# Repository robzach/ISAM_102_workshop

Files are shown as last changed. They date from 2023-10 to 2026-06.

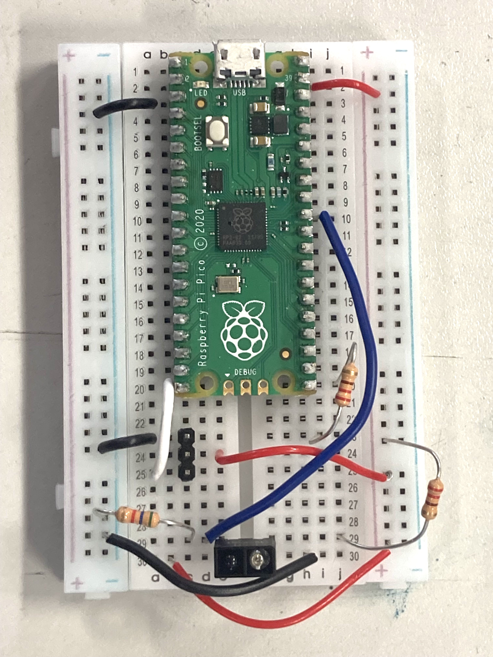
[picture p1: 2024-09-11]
product documentation images/Raspberry Pi Pico.jpg

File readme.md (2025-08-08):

# ISAM 102 Workshop

This repository contains files relevant to the ISAM 102 Workshop, offered as part of the [ISAM (International Symposium on Academic Makerspaces)](https://isam2025.hemi-makers.org/) conference hosted at the University of California, Berkeley on August 6, 2025.

## Key links

* [The workshop slide deck](https://docs.google.com/presentation/d/1lfgx7r61DBWelSqBV9T8WLAmH33UfCxg_Bofop4bHoo/edit?usp=sharing) gives a good overview of the project
* [Bill of materials](https://docs.google.com/spreadsheets/d/1Q51IumBE_j06Qix7HolaOQdSv1IBVW_yVcd7gR8xeUc/edit?usp=sharing) including costs and sources
* Most design files are contained in this repo, organized by the design software used. Our Fusion designs are viewable (and downloadable) below:
  + [Full assembly](https://a360.co/4ouuBFh)
  + [Updated chassis base](https://a360.co/45b6XpY)

## Workshop leaders

* [Robert Zacharias](https://www.andrew.cmu.edu/user/rzachari), Assistant Teaching Professor, Entertainment Technology Center and IDeATe (Integrative Design, Arts, and Technology), Carnegie Mellon University
* [Bill Nace](https://www.ece.cmu.edu/directory/bios/nace-bill.html), Teaching Professor, Electrical and Computer Engineering, Carnegie Mellon University

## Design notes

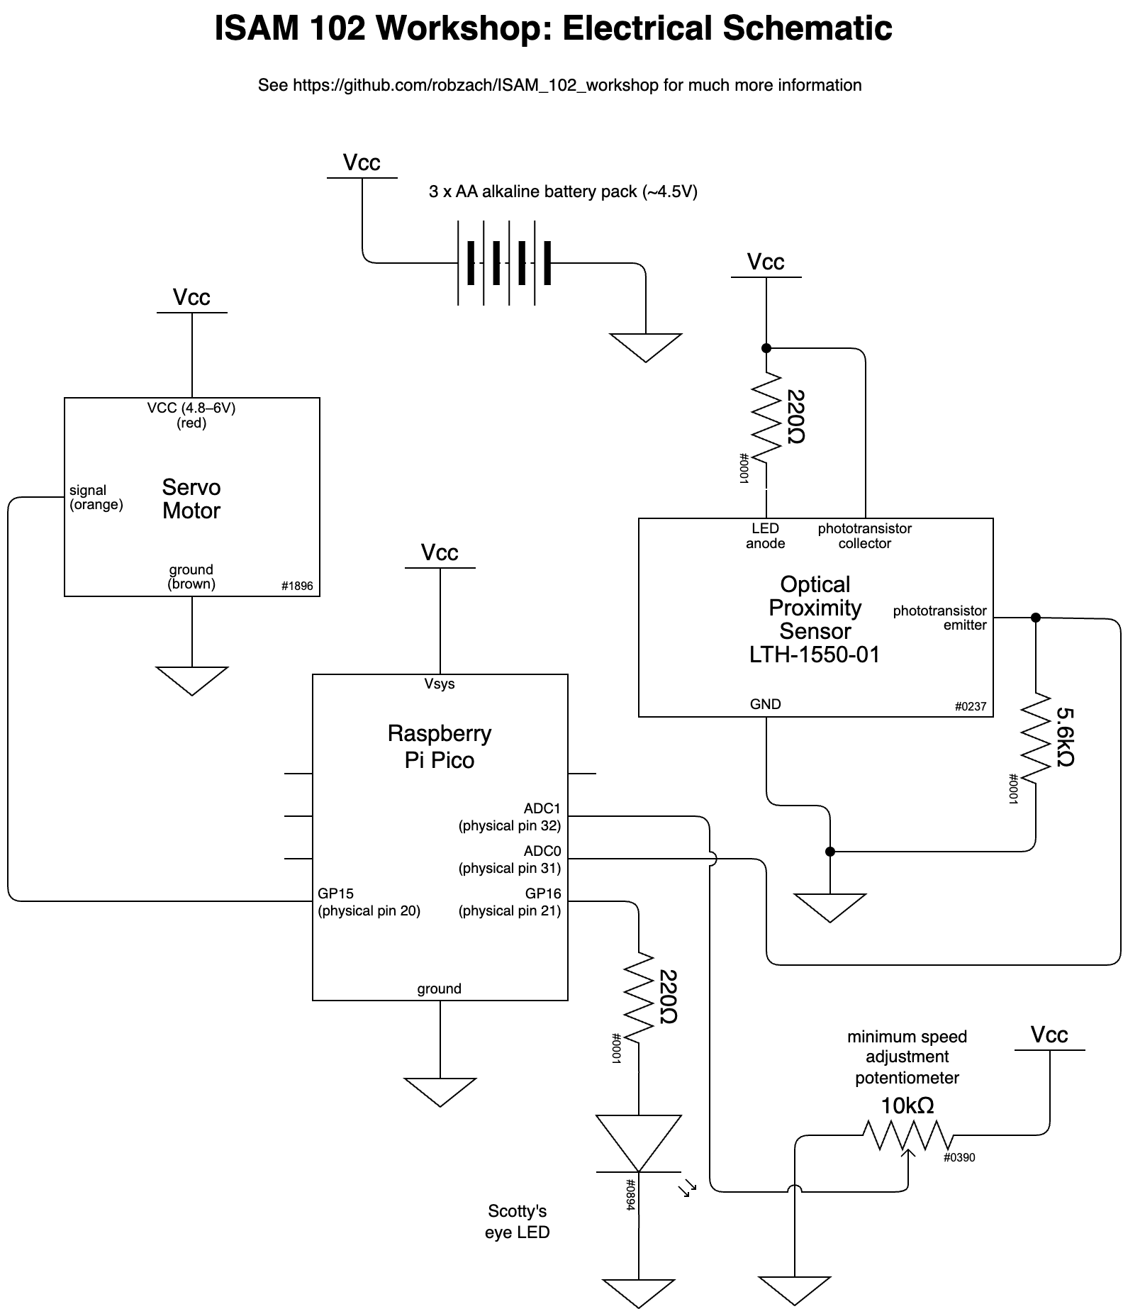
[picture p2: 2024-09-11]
design source files/Draw.ioref.org/ISAM 102 schematic.drawio.png

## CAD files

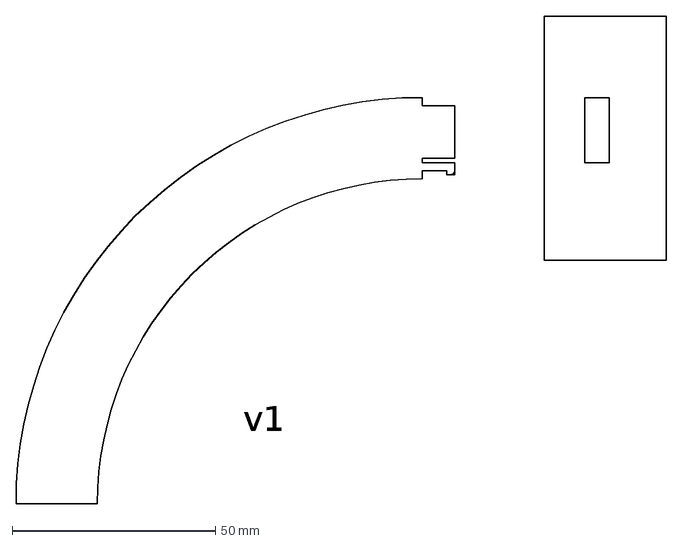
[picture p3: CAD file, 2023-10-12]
design source files/LibreCAD/spring tab 9-22-23.dxf
v1

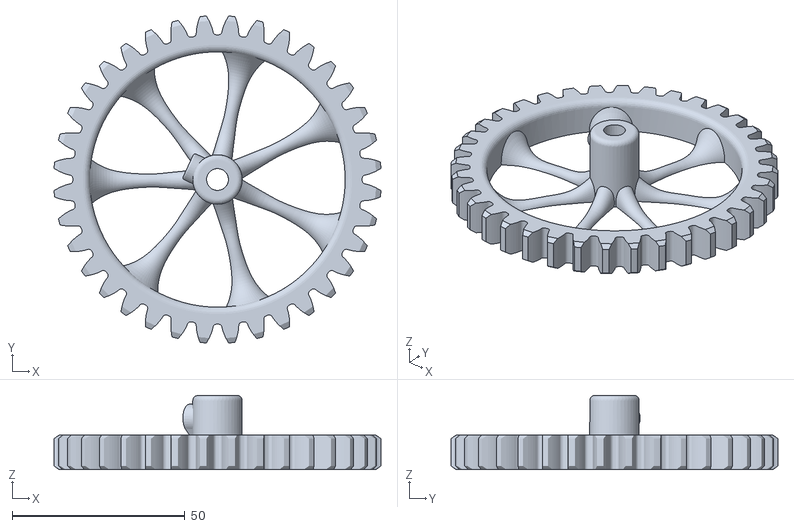
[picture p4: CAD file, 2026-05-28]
production files/D6_gear36Tooth.stl
94.8 x 94.8 x 21.5

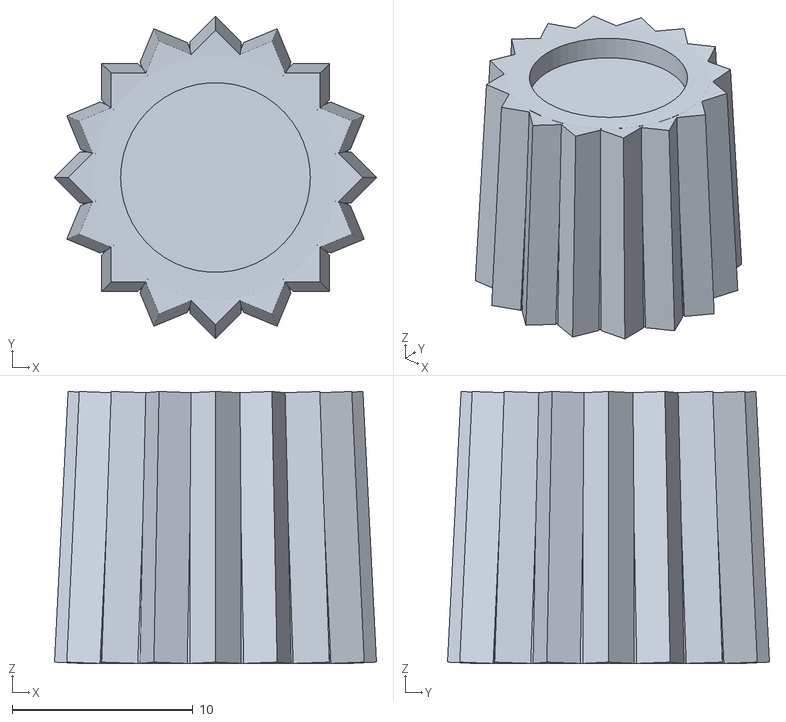
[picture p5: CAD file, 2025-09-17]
production files/knobs/knob_h15_t10_c1.stl
17.8 x 17.8 x 15.1

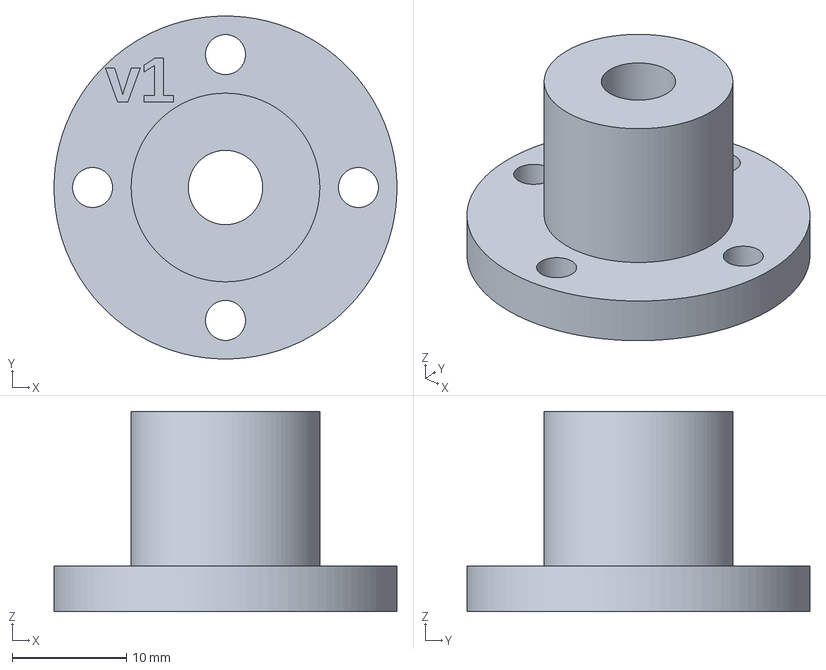
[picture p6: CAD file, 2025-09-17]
production files/D7_shaftHubNoClamp.3mf
30.0 x 30.0 x 17.5 mm

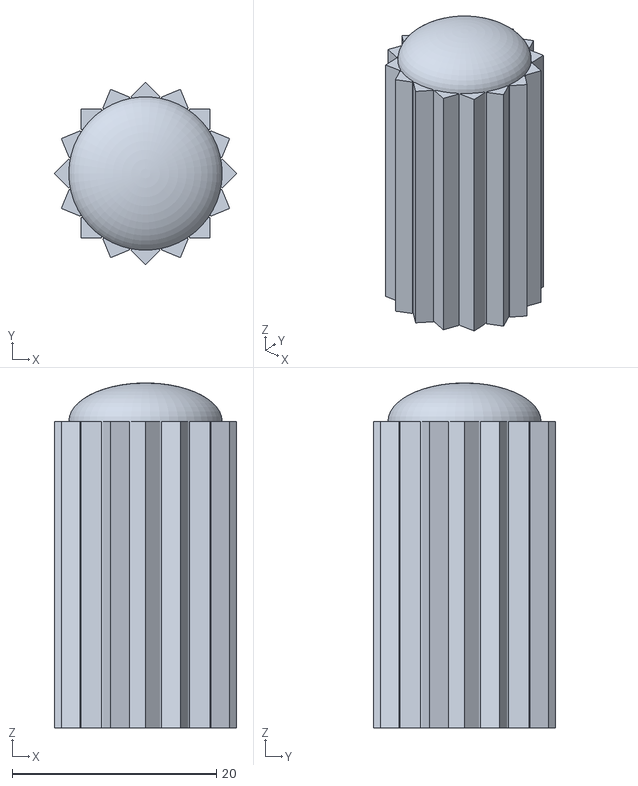
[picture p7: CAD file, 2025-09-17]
production files/knobs/knob_h30_t0_c2.stl
17.8 x 17.8 x 33.7

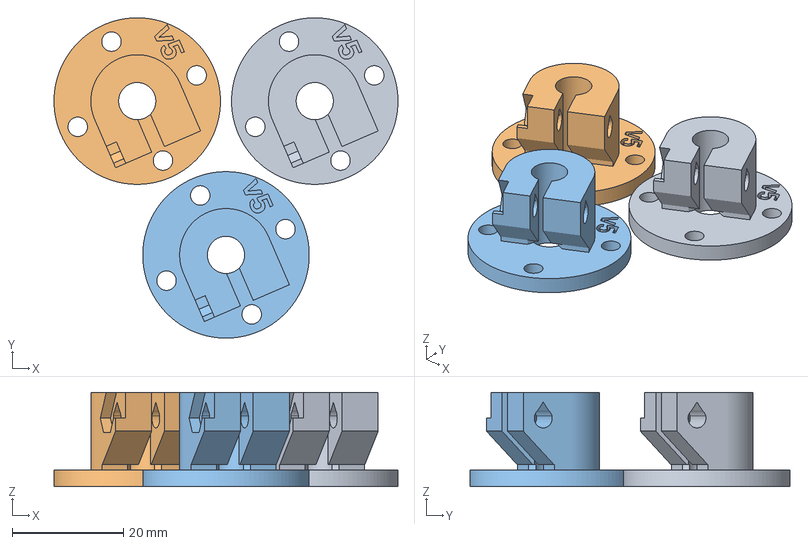
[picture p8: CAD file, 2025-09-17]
production files/D1_shaftHubClamping.3mf
62.0 x 57.7 x 17.0 mm
parameterized hub design v5.stl x 3

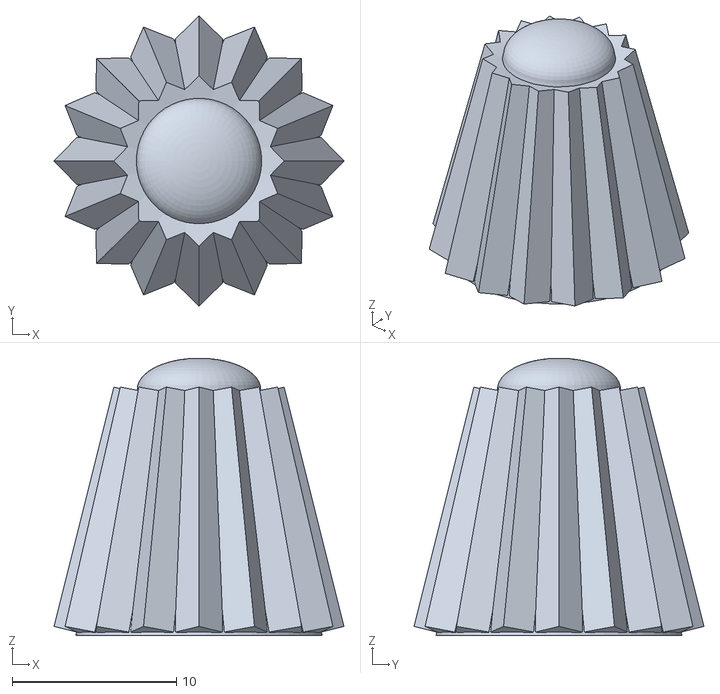
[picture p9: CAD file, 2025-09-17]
production files/knobs/knob_h15_t50_c2.stl
17.6 x 17.6 x 16.9

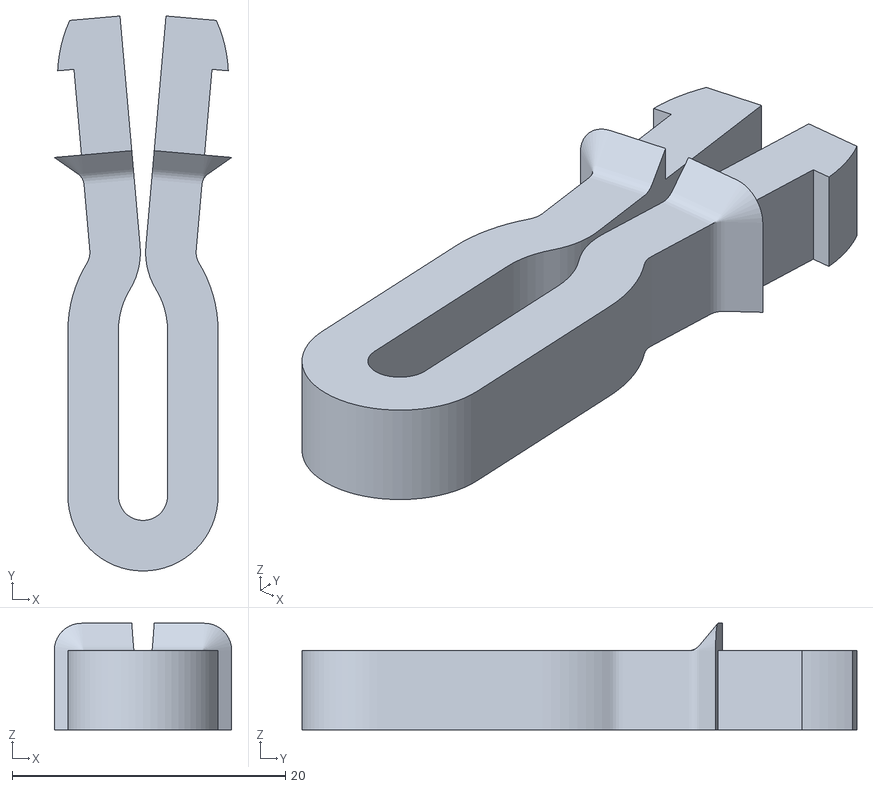
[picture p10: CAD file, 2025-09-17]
production files/D2a_smallTailLoop.stl
13.0 x 40.6 x 7.80

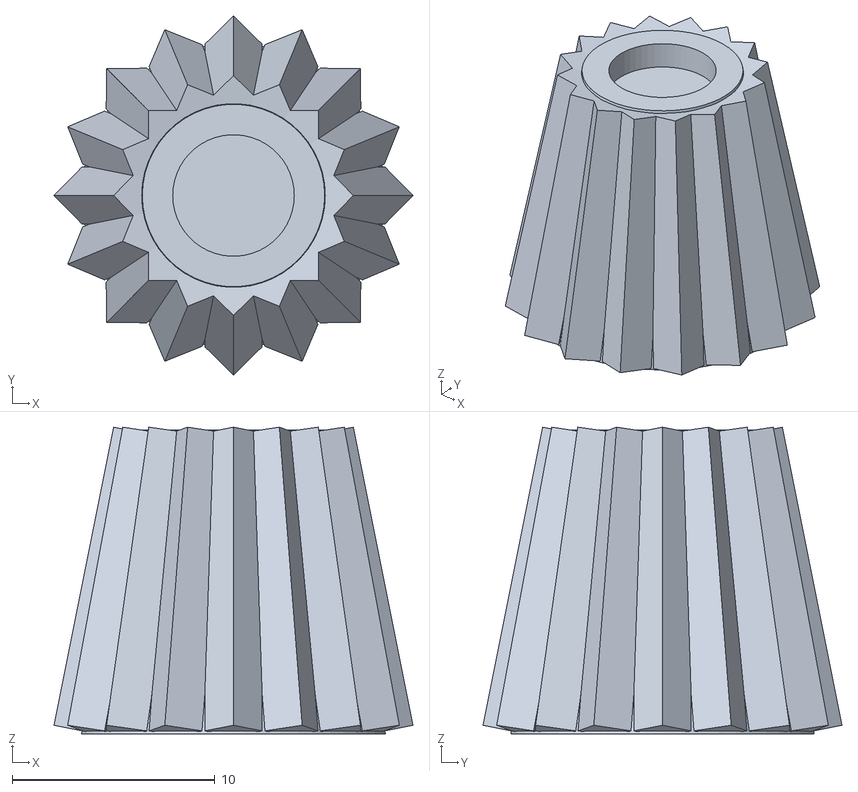
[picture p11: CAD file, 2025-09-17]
production files/knobs/knob_h15_t40_c1.stl
17.7 x 17.7 x 15.1

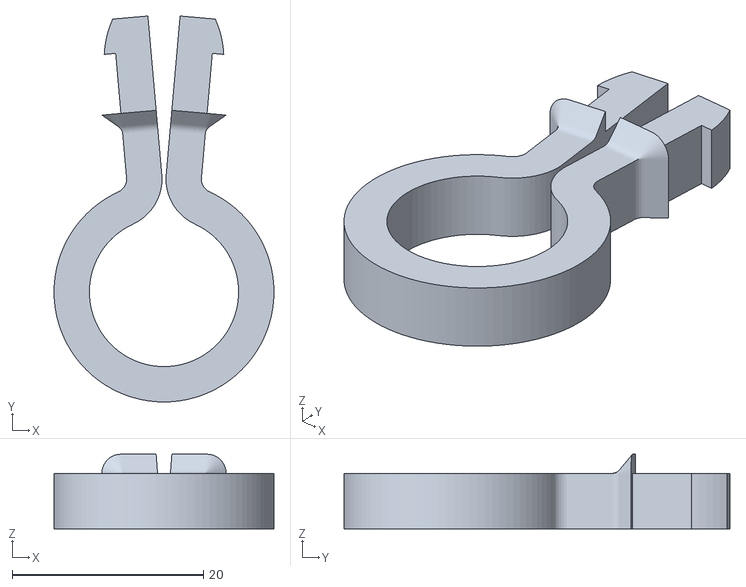
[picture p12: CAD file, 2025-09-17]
production files/D2b_circularTailLoop.stl
23.0 x 40.4 x 7.80

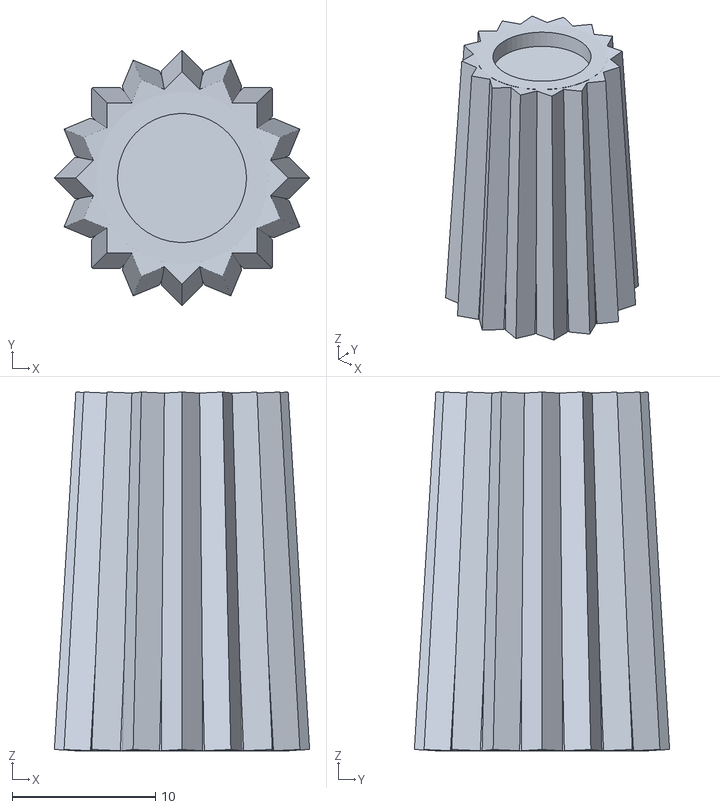
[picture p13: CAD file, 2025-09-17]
production files/knobs/knob_h25_t20_c1.stl
17.8 x 17.8 x 25.1

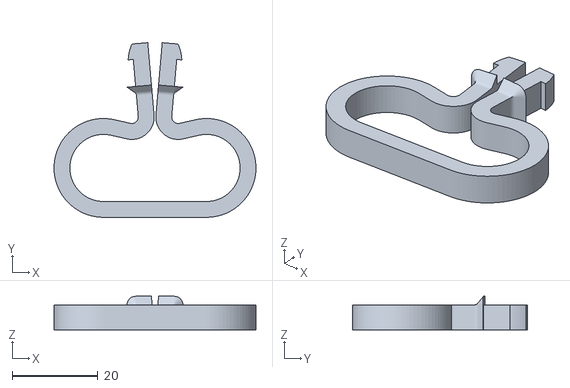
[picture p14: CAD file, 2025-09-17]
production files/D2c_largeTailRing.stl
47.0 x 40.6 x 7.80

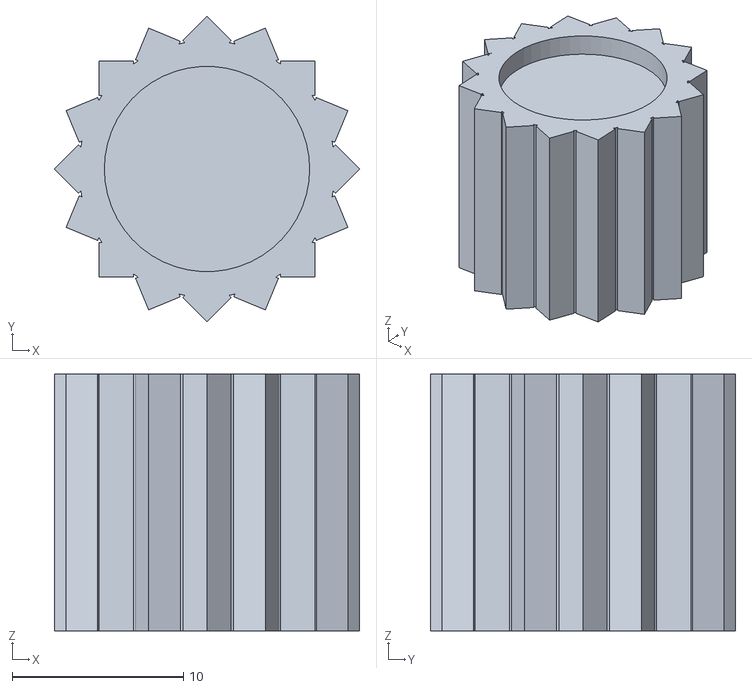
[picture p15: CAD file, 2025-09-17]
production files/knobs/knob_h15_t0_c1.stl
17.8 x 17.8 x 15.0

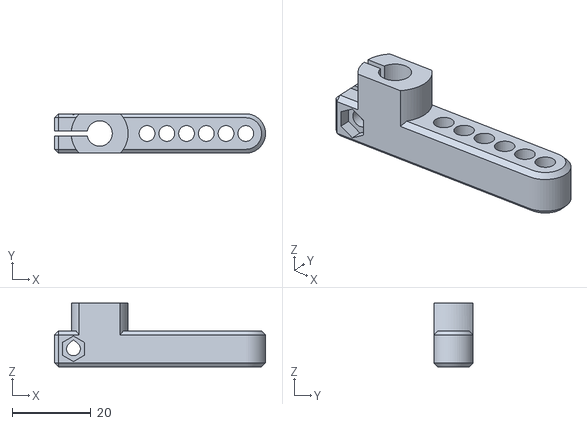
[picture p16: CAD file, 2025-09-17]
production files/D3_tailRotor.stl
53.4 x 10.0 x 16.1

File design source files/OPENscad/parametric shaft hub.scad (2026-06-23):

/*  Parametric shaft hub generator

    Builds a simple hub with clamping, set screw, or plain mounting to the shaft

    Adjust any variables to customize geometry, or use Customizer feature to do the same
   
    Released to the public domain by the author 8/7/24

    Robert Zacharias, rzachari@andrew.cmu.edu
    */
   
/* [Clamp style and overall dimensions] */

//  "roundClamp" gives you a hole for a clamping bolt and nut, and matching relief cuts, good for a smooth shaft; "squaredClamp" adds a large flat which uses more material but gives you a stronger grip on the shaft; "setScrew" gives you one hole facing into the shaft and no relief cuts, good for a shaft with a flat; "none" leaves an uncut cylinder, which could work for a press fit onto a splined shaft
clampingDesign = "squaredClamp"; // [roundClamp, squaredClamp, setScrew, none]

// modify to remove overhangs shallower than 45º
optimizeFor3Dprinting = true;

// diameter of base that will face surface
baseDiameter = 30;
// height of base that will face surface
baseHeight = 3;

// thickness of raised portion that will clamp shaft
shaftClampWallThickness = 5;
// height of raised portion that will clamp shaft
shaftClampHeight = 14;

// clearance for through shaft
shaftDiameter = 6.7;

/* [Mounting holes] */

// mounting holes (0 to however many you want)
numberMountingHoles = 4; // [0:10]
mountingHolesDiameter = 3.5; // [2:.1:5]

// position mounting holes at the midpoint between the base diameter and outer clamp wall
automaticMountingHolePlacement = true;

// specify a mounting hole distance from center if you prefer not to do it automatically
manualHoleDist = 12;

holeDist = automaticMountingHolePlacement
? ((shaftDiameter/2 + shaftClampWallThickness) + (baseDiameter/2)) / 2
: manualHoleDist;

/* [Clamping bolt options] */

// move the clamping bolt towards or away from the shaft; 1 = centered across thickness of clamp wall, lower values are closer to shaft
clampBoltLateralPositionAdjustment = 0.9; // [0.8:0.05:1]

// move the clamping bolt up or down—especially useful if you're optimizing for 3D printing and wish to move the bolt hole away from the chamfered clamp wall
clampBoltVerticalPositionAdjustment = 0; // [0:1:5]

// slot to separate moving part of clamp from base
clampBaseCutoutHeight = 1;

// slot for clamping clearance
clampClearanceWidth = 1.5; // [0.5:0.25:5]

// imperial fractions are baked into customizer values below as rounded
// to nearest thousandth (I can't feed the customizer fractions in its
// inline format)

// hole for clamping bolt (or set screw)
clampingBoltDiameter = 3.5; // [3:M3, 4:M4]
clampingBoltCounterboreDiameter = 5.5; // [5.5:M3]
clampingBoltCounterboreAdditionalInsetDepth = 1;
clampingNutHeightFlatToFlat = 5.5; // [5.5:M3, 7:M4, 0.344:#8-32, 0.438:1/4-20]
// how much additional clearance to give around periphery of clamping nut (to give it a loose fit)
clampingNutClearance = 0.5; // [0:0.25:5]
clampingNutDepth = 2.4; // [2.4:M3, 3.2:M4, 0.125:#8-32, 0.219:1/4-20]
// move the nut cutout deeper into the clamp
clampingNutAdditionalInsetDepth = 0;
// typically ~0.75 for "roundClamp", 1 for "squaredClamp"; higher for shallower insets
clampingHardwareProportionalDepth = 1; // [0.25:0.1:1.5]

/* [Emboss version text] */
// emboss text of part version onto top of base
embossVersion = true; //
version = "v7";


/* [Rendering accuracy] */
// OpenSCAD rendering accuracy (higher draws more faces)
$fn = 100; // [10:10:300]

/* [Hidden] */
// small value to move things a smidge off of a surface
epsilon = 0.001;


// you can't create and then modify a global variable
// so instead, this function is used to move clamping hardware
// upwards when optimizing for 3D printing
function clampingHardwareAdjustmentFor3Dprinting() = optimizeFor3Dprinting ? 1.5 : 2;
usuallyTwo = clampingHardwareAdjustmentFor3Dprinting();          

           
difference (){

    // base plus clamping part
    union (){        
               
        // base
        cylinder(h=baseHeight,r=baseDiameter/2);
       
        // clamping part
        translate([0,0,baseHeight])
            cylinder(h=shaftClampHeight,r=shaftDiameter/2+shaftClampWallThickness);
       
        // add square shoulders if requested
        if (clampingDesign == "squaredClamp"){
            translate([0,-(shaftDiameter/2 + shaftClampWallThickness),baseHeight])
                cube([shaftDiameter/1.5+shaftClampWallThickness, shaftDiameter+shaftClampWallThickness*2, shaftClampHeight]);
        }
    }

    // shaft hole
    translate([0,0,-epsilon]) cylinder(h=baseHeight+shaftClampHeight+(epsilon*2), r=shaftDiameter/2);
   
    // array of mounting holes
    if (numberMountingHoles > 0){
        for (i=[0:numberMountingHoles])
            rotate([0,0,i*(360/numberMountingHoles)]){
                // single mounting hole
                translate([holeDist,0,-epsilon])
                    cylinder (h=baseHeight+2*epsilon, r=mountingHolesDiameter/2);
        }
    }
   
    if (optimizeFor3Dprinting && (clampingDesign == "squaredClamp" || clampingDesign == "roundClamp")){
           
               
        // teardrop cutout at top of clamping bolt hole
        // this prevents overhang greater than 45º
        translate([(shaftDiameter/2 + shaftClampWallThickness/2) * clampBoltLateralPositionAdjustment, 0, baseHeight + shaftClampHeight/usuallyTwo + (clampingBoltDiameter / 8) + clampBoltVerticalPositionAdjustment]) // the last value there is empirical and wonky
            rotate([90, 0, 0])
                linear_extrude(baseDiameter, center = true, convexity = 1)
                    polygon([[-clampingBoltDiameter/2, 0], [clampingBoltDiameter/2, 0], [0, (clampingBoltDiameter/2)*sqrt(2)]]);
               
        // additional equilateral triangle cutout at top of bolt cutout to prevent overhang
               translate([(shaftDiameter/2 + shaftClampWallThickness/2) * clampBoltLateralPositionAdjustment, -(shaftClampWallThickness+shaftDiameter/2)+(clampingNutDepth/2)-epsilon, baseHeight + shaftClampHeight/usuallyTwo + clampBoltVerticalPositionAdjustment])
            rotate([90, 0, 0])
                linear_extrude(clampingNutDepth, center = true, convexity = 1)
                    polygon([[-clampingNutHeightFlatToFlat/2, 0], [clampingNutHeightFlatToFlat/2, 0], [0, clampingNutHeightFlatToFlat/2 * sqrt(3)]]);
               
        if (clampingDesign == "squaredClamp"){
            // 45º chamfer at base of clamping body
            translate([(shaftDiameter/1.5 + shaftClampWallThickness), 0, baseHeight + clampBaseCutoutHeight])
                rotate([90, 0, 0])
                    linear_extrude(baseDiameter, center = true, convexity = 1)
                        polygon([[epsilon, epsilon], [epsilon, shaftClampWallThickness + clampBaseCutoutHeight + epsilon], [-(shaftClampWallThickness + clampBaseCutoutHeight), 0]]);
            
            // remove redundant upper outer piece of nut cutout
            translate([(shaftDiameter/2 + shaftClampWallThickness/2) * clampBoltLateralPositionAdjustment, -(shaftClampWallThickness+shaftDiameter/2)+(clampingNutDepth)-epsilon, baseHeight + shaftClampHeight/usuallyTwo + clampBoltVerticalPositionAdjustment])
            mirror([0,1,0])
                cube(shaftClampWallThickness, center = false);
        }
       
        if (clampingDesign == "roundClamp"){
            // 45º chamfer at base of clamping body
            translate([(shaftDiameter/2 + shaftClampWallThickness), 0, baseHeight + clampBaseCutoutHeight])
                rotate([90, 0, 0])
                    linear_extrude(baseDiameter, center = true, convexity = 1)
                        polygon([[epsilon, epsilon], [epsilon, shaftClampWallThickness + shaftDiameter/2 + epsilon], [-(shaftClampWallThickness + shaftDiameter/2), 0]]);
        }
           
        }
       
       
    if (clampingDesign == "roundClamp" || clampingDesign == "squaredClamp"){
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

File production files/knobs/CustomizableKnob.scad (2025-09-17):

/*

Trying to get the OpenSCAD CLI to make a bunch of versions of this with different parameters; this command is working:

/Applications/OpenSCAD.app/Contents/MacOS/OpenSCAD -D KnobHeight=20 -D TaperPercentage=30 -D CapType=2 -o knob.stl CustomizableKnob.scad

The -D flags are used to change the values of variables in the design.




I used ChatGPT to generate the script to use for loops to run through a list of possible values. My prompt to ChatGPT:

"I have a terminal command that works, "/Applications/OpenSCAD.app/Contents/MacOS/OpenSCAD -D KnobHeight=20 -D TaperPercentage=30 -D CapType=2 -o knob.stl CustomizableKnob.scad". I now want to write a loop that will change some of the variables I'm feeding that function so that I, for instance, get knobs with heights of 16, 18, 20, 22, 24, and 26, and taper percentages of 0, 5, 10, 15, 20, 25, 30, 35, 40, and 50. The files that are created should have sequential values, e.g. knob1.stl, knob2.stl, etc."


I had a few back-and-forths to fiddle with it but here is the final script I am running, called generateKnobs.sh:

//script start

    #!/bin/bash
    
    # Set path to OpenSCAD binary and source file
    OPENSCAD="/Applications/OpenSCAD.app/Contents/MacOS/OpenSCAD"
    SCADFILE="CustomizableKnob.scad"
    
    # Loop over KnobHeight values
    for height in 15 20 25 30; do
      # Loop over TaperPercentage values
      for taper in 0 10 20 30 40 50; do
        for captype in 1 2; do
          
          # Construct output filename with parameter values
          outfile="knob_h${height}_t${taper}_c${captype}.stl"
    
          # Run OpenSCAD command
          "$OPENSCAD" -D KnobHeight=$height -D TaperPercentage=$taper -D CapType=$captype -o "$outfile" "$SCADFILE"
    
          echo "Generated $outfile"
        done
      done
    done

//script end

- Robert Zacharias, rzachari@andrew.cmu.edu 8/1/25
released under a CC-BY license, following original author's move (see below)


The actual source for the knob generator below is "Customizable Knob!" from charliearmorycom, dated Feb. 25, 2013, available as thing #54024 at Thingiverse: <https://www.thingiverse.com/thing:54024>. The original author released it under a CC-BY license.

*/

//////////////////////////
// Customizable settings
//////////////////////////


// Diameter of the hole on the bottom (in mm).
HoleDiameter = 6.15;

// Depth of the hole in the bottom (in mm).  If you want the hole to go all the way through then set this to a number larger than the total height of the object.
HoleDepth = 8;

// If you want a D-shaped hole, set this to the thickness of the flat side (in mm).  Larger values for the flat make the hole smaller.
HoleFlatThickness = 0;

// Height (in mm).  If dome cap is selected, it is not included in height.  The shaft length is also not counted.
KnobHeight = 10;

// Diameter of base of round part of knob (in mm).  (Knurled ridges are not included in this measurement.)
KnobDiameter = 15;

// Shape of top of knob.  "Recessed" type can be painted.
CapType = 1;	// [0:Flat, 1:Recessed, 2:Dome]

// Do you want a large timer-knob style pointer?
TimerKnob=0;	// [0:No, 1:Yes]

// Would you like a divot on the top to indicate direction?
Pointer1 = 0;	// [0:No, 1:Yes]

// Would you like a line (pointer) on the front to indicate direction?
Pointer2 = 0;	// [0:No, 1:Yes]

// Do you want finger ridges around the knob?
Knurled = 1;	// [0:No, 1:Yes]

// 0 = A cylindrical knob, any other value will taper the knob.
TaperPercentage = 20;		// [0:0%, 10:10%, 20:20%, 30:30%, 40:40%, 50:50%]

// Width of "dial" ring (in mm).  Set to zero if you don't want the ring.
RingWidth = 0;

// The number of markings on the dial.  Set to zero if you don't want markings.  (RingWidth must be non-zero.)
RingMarkings = 10;

// diameter of the hole for the setscrew (in mm).  If you don't need a hole, set this to zero.
ScrewHoleDiameter = 0;

// Length of the shaft on the bottom of the knob (in mm).  If you don't want a shaft, set this value to zero.
ShaftLength = 0;

// Diameter of the shaft on the bottom of the knob (in mm).  (ShaftLength must be non-zero.)
ShaftDiameter = 10;

// Would you like a notch in the shaft?  It can be used for a press-on type knob (rather than using a setscrew).  (ShaftLength must be non-zero.)
NotchedShaft = 0;	// [0:No, 1:Yes]



//////////////////////////
//Advanced settings
//////////////////////////

RingThickness = 5*1;
DivotDepth = 1.5*1;
MarkingWidth = 1.5*1;
DistanceBetweenKnurls = 3*1;
TimerKnobConst = 1.8*1;



//////////////////////////
//Calculations
//////////////////////////

PI=3.14159265*1;
KnobMajorRadius = KnobDiameter/2;
KnobMinorRadius = KnobDiameter/2 * (1 - TaperPercentage/100);
KnobRadius = KnobMinorRadius + (KnobMajorRadius-KnobMinorRadius)/2;
KnobCircumference = PI*KnobDiameter;
Knurls = round(KnobCircumference/DistanceBetweenKnurls);
Divot=CapType;

TaperAngle=asin(KnobHeight / (sqrt(pow(KnobHeight, 2) +
		pow(KnobMajorRadius-KnobMinorRadius,2)))) - 90;

DivotRadius = KnobMinorRadius*.4;


union()
{
translate([0, 0, (ShaftLength==0)? 0 : ShaftLength-0.001])
difference()
{
union()
{
	// Primary knob cylinder
	cylinder(h=KnobHeight, r1=KnobMajorRadius, r2=KnobMinorRadius,
			$fn=50);
	
	if (Knurled)
		for (i=[0 : Knurls-1])
			rotate([0, 0, i * (360/Knurls)])
				translate([KnobRadius, 0, KnobHeight/2])
					rotate([0, TaperAngle, 0]) rotate([0, 0, 45])
						cube([2, 2, KnobHeight+.001], center=true);

 	if (RingMarkings>0)
		for (i=[0 : RingMarkings-1])
			rotate([0, 0, i * (360/RingMarkings)])
				translate([KnobMajorRadius + RingWidth/2, 0, 1])
					cube([RingWidth*.5, MarkingWidth, 2], center=true);		
	
	if (Pointer2==1)
		translate([KnobRadius, 0, KnobHeight/2-2])
			rotate([0, TaperAngle, 0])
				cube([8, 3, KnobHeight], center=true);		

	if (RingWidth>0)
		translate([0, 0, RingThickness/2])
			cylinder(r1=KnobMajorRadius + RingWidth, r2=KnobMinorRadius,
					h=RingThickness, $fn=50, center=true);

	if (Divot==2)
		translate([0, 0, KnobHeight])
			difference()
			{
				scale([1, 1, 0.5])
					sphere(r=KnobMinorRadius, $fn=50, center=true);

				translate([0, 0, 0-(KnobMinorRadius+.001)])
					cube([KnobMinorRadius*2.5, KnobMinorRadius*2.5,
							KnobMinorRadius*2], center=true);
			}

	if (TimerKnob==1) intersection()
		{
			translate([0, 0, 0-(KnobDiameter*TimerKnobConst) + KnobHeight])
			sphere(r=KnobDiameter*TimerKnobConst, $fn=50, center=true);		
	
			translate([0-(KnobDiameter*TimerKnobConst)*0.1, 0,
					KnobHeight/2])
				scale([1, 0.5, 1])
					cylinder(h=KnobHeight, r=(KnobDiameter*TimerKnobConst) *
							0.8, $fn=3, center=true);
		}
}

// Pointer1: Offset hemispherical divot
if (Pointer1==1)
	translate([KnobMinorRadius*.55, 0, KnobHeight + DivotRadius*.6])
		sphere(r=DivotRadius, $fn=40);

// Divot1: Centered cylynrical divot
if (Divot==1)
	translate([0, 0, KnobHeight])
		cylinder(h=DivotDepth*2, r=KnobMinorRadius-1.5, $fn=50,
				center=true);

if (ShaftLength==0)
{
	// Hole for shaft
	translate([0, 0, HoleDepth/2 - 0.001])
		difference()
		{
			cylinder(r=HoleDiameter/2, h=HoleDepth, $fn=20,
					center=true);
	
			// Flat for D-shaped hole
			translate([(0-HoleDiameter)+HoleFlatThickness, 0, 0])
				cube([HoleDiameter, HoleDiameter, HoleDepth+.001],
						center=true);
		}
	
	// Hole for setscrew
	if (ScrewHoleDiameter>0)
		translate([0 - (KnobMajorRadius+RingWidth+1)/2, 0,
				HoleDepth/2])
			rotate([0, 90, 0])
			cylinder(h=(KnobMajorRadius+RingWidth+1),
					r=ScrewHoleDiameter/2, $fn=20, center=true);
}

// Make sure bottom ends at z=0
translate([0, 0, -10])
	cube([(KnobMajorRadius+RingWidth) * 3,
			(KnobMajorRadius+RingWidth) * 3, 20], center=true);
}

if (ShaftLength>0)
	difference()
	{
		translate([0, 0, ShaftLength/2])
			cylinder(h=ShaftLength, r=ShaftDiameter/2, $fn=20,
					center=true);

		if (NotchedShaft==1)
		{
			cube([HoleDiameter/2, ShaftDiameter*2, ShaftLength],
					center=true);
		}

		// Hole for shaft
		translate([0, 0, HoleDepth/2 - 0.001])
			difference()
			{
				cylinder(r=HoleDiameter/2, h=HoleDepth, $fn=20,
						center=true);
		
				// Flat for D-shaped hole
				translate([(0-HoleDiameter)+HoleFlatThickness, 0, 0])
					cube([HoleDiameter, HoleDiameter, HoleDepth+.001],
							center=true);
			}
		
		// Hole for setscrew
		if (ScrewHoleDiameter>0)
			translate([0 - (KnobMajorRadius+RingWidth+1)/2, 0,
					HoleDepth/2])
				rotate([0, 90, 0])
				cylinder(h=(KnobMajorRadius+RingWidth+1),
						r=ScrewHoleDiameter/2, $fn=20, center=true);
	}
}

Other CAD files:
production files/knobs/knob_h25_t30_c1.stl
production files/knobs/knob_h25_t40_c1.stl
production files/L2_Support_Arch.dxf
production files/knobs/knob_h30_t50_c1.stl
production files/L10_Pointy_Cam.dxf
production files/L11_RoundCam.dxf
production files/L12_SquareCam.dxf
production files/L13_Sidewall.dxf
production files/L14_SpiralCam.dxf
production files/L1_Acrylic_Wall(1).dxf
production files/L1_Acrylic_Wall.dxf
production files/L3_Base.dxf
production files/L4_Gear_12Tooth.dxf
production files/L5_L6_Gears.dxf
production files/L7_Dog_Body.dxf
production files/L8_Dog_Head.dxf
production files/L9_PentaCam.dxf
production files/knobs/knob_h15_t0_c2.stl
production files/knobs/knob_h15_t10_c2.stl
production files/knobs/knob_h15_t20_c1.stl
production files/knobs/knob_h15_t20_c2.stl
production files/knobs/knob_h15_t30_c1.stl
production files/knobs/knob_h15_t30_c2.stl
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

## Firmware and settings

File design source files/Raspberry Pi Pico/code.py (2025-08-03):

"""
Scotty Dog mechatronic device, Raspberry Pi Pico firmware
built for "ISAM 102" workshop at the International Symposium of Academic Makerspaces,
held at the University of California at Berkeley, August 6, 2025

This sketch reads an infrared proximity sensor as an input, and uses the values
observed to change the speed of a continuous servo motor output. Additionally, it
reads a potentiometer to set the minimum output speed of the servo motor, and blinks
an external LED which is the Scotty Dog's eye.

Much more information, including images and electrical schematics, available at
https://github.com/robzach/ISAM_102_workshop

Pin mapping:

pin number  physical pin    role        description
-----------------------------------------------------------------------
GP25        (none)          output      built-in green LED
GP16        21              output      external bi-color LED leg 1, Scotty dog's eye
GP17        22              output      external bi-color LED leg 2, Scotty dog's eye 
GP15        20              output      continuous servo motor signal
A0          31              input       IR proximity sensor
A1          32              input       potentiometer


Incorporates CC BY 4.0 code from Garth Zeglin's 16-223 course website sketches:
analog_input.py (https://courses.ideate.cmu.edu/16-223/f2024/text/code/pico-analog-io.html#analog-input)
servo_step.py (https://courses.ideate.cmu.edu/16-223/f2024/text/code/pico-servo.html#servo-step)

CC BY 4.0, 2025, Robert Zacharias, rzachari@andrew.cmu.edu

"""

import board, math, time, pwmio, analogio, digitalio, adafruit_simplemath

# set up built-in green LED for output
internal_led = digitalio.DigitalInOut(board.LED)  # GP25, no physical pin
internal_led.direction = digitalio.Direction.OUTPUT

# additional LED outputs (Scotty eye)
external_led_1 = digitalio.DigitalInOut(board.GP16)   # physical pin #21
external_led_1.direction = digitalio.Direction.OUTPUT
external_led_2 = digitalio.DigitalInOut(board.GP17)   # physical pin #22
external_led_2.direction = digitalio.Direction.OUTPUT

# Create a PWMOut object on Pin GP15 to drive the servo. The frequency argument
# specifies the pulse repetition rate in Hz (pulses per second).
servo = pwmio.PWMOut(board.GP15, duty_cycle=0, frequency=50)  # physical pin #20

# IR proximity sensor
sensor = analogio.AnalogIn(board.A0)    # physical pin #31

# potentiometer
pot = analogio.AnalogIn(board.A1)       # physical pin #32

fastblink = 0.01    # one tenth of a second
slowblink = 0.5     # two milliseconds
lastBlink = 0       # the last time the blinking LED changed states

highest = 0         # highest-yet observed value
lowest = 65536      # lowest-yet observed value

lastUpdate = 0
interval = 1        # delay between sending serial updates (seconds)

stopServoAngle = 90      # 90º drives continuous servo to stop
fastestServoAngle = 0     # 0º drives the servo at its fastest counterclockwise speed


#### servo function ####

#--------------------------------------------------------------------------------
# Define a function to issue a servo command by updating the PWM signal output.
# This function maps an angle specified in degrees between 0 and 180 to a servo
# command pulse width between 1 and 2 milliseconds, and then to the
# corresponding duty cycle fraction, specified as a 16-bit fixed-point integer.

def servo_write(servo, angle, debug=False):
    # calculate the desired pulse width in units of seconds
    pulse_width  = 0.001 + angle * (0.001 / 180.0)

    # fetch the current pulse repetition rate from the hardware driver
    pulse_rate = servo.frequency

    # calculate the duration in seconds of a single pulse cycle
    cycle_period = 1.0 / pulse_rate

    # calculate the desired ratio of pulse ON time to cycle duration
    duty_cycle   = pulse_width / cycle_period

    # convert the ratio into a 16-bit fixed point integer
    duty_fixed   = int(2**16 * duty_cycle)

    # limit the ratio range and apply to the hardware driver
    servo.duty_cycle = min(max(duty_fixed, 0), 65535)

    # print some diagnostics to the console
    if debug:
        print(f"Driving servo to angle {angle}")
        print(f" Pulse width {pulse_width} seconds")
        print(f" Duty cycle {duty_cycle}")
        print(f" Command value {servo.duty_cycle}\n")

#### main loop ####

while True:

    # read the IR sensor once per cycle
    sensor_val = sensor.value

    # read the potentiometer once per cycle
    pot_val = pot.value

    # update slowestServoAngle based on current potentiometer position
    slowestServoAngle = adafruit_simplemath.map_range(
        pot_val,
        0,
        65535,
        stopServoAngle,
        fastestServoAngle)


    # set highest and lowest levels based on observations
    if sensor_val > highest:
        highest = sensor_val

    if sensor_val < lowest:
        lowest = sensor_val


    # calculate servo command
    servoPos = adafruit_simplemath.map_range(
        sensor_val,
        lowest,
        highest,
        slowestServoAngle,
        fastestServoAngle)

    # calculate blink rate for on-board LED at varying rate as coarse indicator
    blinkInterval = adafruit_simplemath.map_range(
        sensor_val,
        lowest,
        highest,
        slowblink,
        fastblink)
        

    # drive servo
    servo_write(servo, servoPos, debug=False)

    # if it's been long enough, toggle LEDs oppositely from each other
    if time.monotonic() > (lastBlink + blinkInterval):
        if internal_led.value == False:
            internal_led.value = True
            external_led_1.value = True
            external_led_2.value = False
        else:
            internal_led.value = False
            external_led_1.value = False
            external_led_2.value = True

        lastBlink = time.monotonic()



    # print serial debugging data every "interval" seconds
    if time.monotonic() > (lastUpdate + interval):
        print("time.monotonic =", time.monotonic(),
            "\tpot_val =", pot_val,
            "\tsensor_val =", sensor_val,
            "\tlowest =", lowest,
            "\thighest =", highest)
        lastUpdate = time.monotonic()

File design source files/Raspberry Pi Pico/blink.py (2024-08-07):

# pico_blink.py

# Raspberry Pi Pico - Blink demo

# Blink the onboard LED and print messages to the serial console.

import board
import time
from digitalio import DigitalInOut, Direction, Pull

#---------------------------------------------------------------
# Set up the hardware: script equivalent to Arduino setup()
# Set up built-in green LED
led = DigitalInOut(board.LED)  # GP25
led.direction = Direction.OUTPUT

#---------------------------------------------------------------
# Run the main loop: script equivalent to Arduino loop()

while True:
    led.value = True
    print("On")
    time.sleep(1.0)

    led.value = False
    print("Off")
    time.sleep(1.0)

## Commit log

2023-10-12 new Scotty driver version
2023-10-12 add BOM link
2023-10-15 modified square clamp design to have triangular rather than rectangular cutout; added properly formed parameters after some variables to allow for easier use of "customizer" tool
    [parametric shaft hub.scad]
2023-10-16 add schematics
2023-10-16 added back smaller rectangular cut to allow for clamping area to flex without tearing away from base
    [parametric shaft hub.scad]
2023-10-16 version for testing 10-16-23
    [parametric shaft hub 10-16-23 1533.stl]
2023-10-16 Added Gears weblink
2023-10-18 adds simple autoranging feature, light-blinking feedback, and Arduino Pro Micro pin mapping
2023-10-18 move servo to pin 9
2023-10-18 change minimum motor speed to 90 so it fully stops
2024-08-01 variety of geometry updates, as well as more user-settable parameters
    [parametric shaft hub.scad]
2024-08-01 update Customizer headings, etc.
    [parametric shaft hub.scad]
2024-08-07 optimizations for 3d printing and other design tweaks
    [parametric shaft hub.scad]
2024-08-07 initial commit of RasPi Pico files
2024-08-07 Rename 10-16-23 cutting 1:4" shaft.JPG to 10-16-23 cutting 0.25 in shaft.JPG because the colon and quote marks aren't legal file name characters on Windows
2024-08-16 updates to blink external LED and read potentiometer to set minimum speed
2024-09-08 update to v5 parameters, used in printing for project, and also add embossed text to customizer
    [parametric shaft hub.scad]
2024-09-11 these servos run the other way, so changed the max angle to 0º
2024-09-11 clearing out 2023 material
    [parameterized hub design v5.stl, parametric shaft hub 10-16-23 1533.stl]
2024-09-11 adding production files labeled with part numbers
    [L10_Pointy_Cam.dxf, L11_RoundCam.dxf, L12_SquareCam.dxf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]
2025-08-03 added 2nd LED output pin (for bi-color LED)
2025-09-17 add missing STLs that came from ancillary Fusion drawings
    [D2a_smallTailLoop.stl, D2b_circularTailLoop.stl, D2c_largeTailRing.stl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]
2025-09-17 add clamping and non-clamping hub 3mf files
    [D1_shaftHubClamping.3mf, D7_shaftHubNoClamp.3mf]
2025-09-17 adding knob folder with all the variant knobs we printed as well as the OpenSCAD source (plus shell script for generating a folder full of variants; see the top comment block of CustomizableKnob.scad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
    [CustomizableKnob.scad, knob_h15_t0_c1.stl, knob_h15_t0_c2.stl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]
2026-05-28 update to v6, adjusting default clamping diameter and tweaking customizer clamping nut values
    [parametric shaft hub.scad]
2026-05-28 36 Tooth gear moved closer to acrylic wall
    [D6_gear36Tooth.stl]
2026-05-31 Converted 12 tooth gear to SVG (Horray for Shaper Utilities)
2026-06-09 change all default values to v7 clamp design; fix slightly-too-small hex nut cutouts
    [parametric shaft hub.scad]
2026-06-09 Increase default clamping nut clearance from 0.2 to 0.5 to match v7
    [parametric shaft hub.scad]
2026-06-23 add customizer option to fix mounting hole placement
    [parametric shaft hub.scad]
2026-10-12 add big schematic
2026-10-12 add printout
2026-10-12 add brackets to fix document links
2026-10-14 add 2026 parametric shaft hub saved parameters
2026-10-14 add all KiCAD sources
